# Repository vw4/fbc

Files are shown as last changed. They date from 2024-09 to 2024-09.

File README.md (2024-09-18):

# Footwell Backlight Controller

- Independent two-channel control with smooth fade transitions
- Delayed switch-off feature (can be disabled via T58b input)
- Low power standby mode

## Schematics

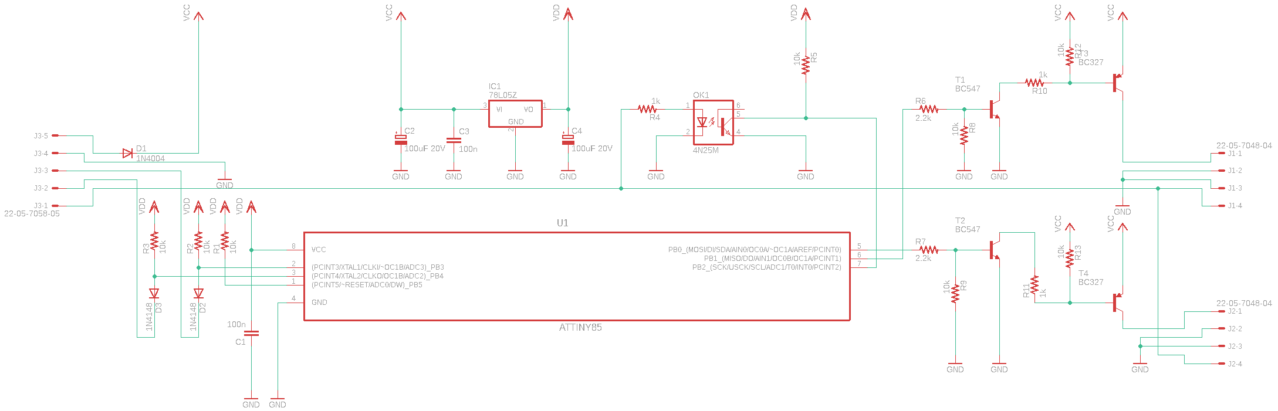
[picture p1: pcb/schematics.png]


## Partlist

### PCB

There are known issues with PCB layout

- The distance between the 4-pin connectors and the mounting holes is shorter by 0.5mm.
- All connectors need to be moved outward by 3.6mm to match the case outline.
- There are errors in the positions of the J1 and J2 labels on the silkscreen; the labels are placed on the solder pads.
- D1 is too close to the J3 connector housing.

| Qty | Value | Device | Package | Parts | Description | MF MPN | OC_FARNELL | OC_NEWARK | PACKAGE  | SUPPLIER |
|-----|---|---|---|---|---|---|---|---|---|---|
| 2 | 100n | Capacitor | C025-025X050 | C1, C3 | ceramic or polyester capacitor | | | | | |
| 2 | 100uF 20V | Capacitor | E3,5-8 | C2, C4 | electrolytic capacitor | | | | | |
| 8 | 10k | Resistor | 0207/10 | R1, R2, R3, R5, R8, R9, R12, R13 | 1/4 Watt, ±5% | | | | | |
| 1 | 1N4004 | 1N4004 | DO41-10 | D1 | DIODE | | | | | |
| 2 | 1N4148 | 1N4148 | DO35-10 | D2, D3 | DIODE | | | | | |
| 3 | 1k | Resistor | 0207/10 | R4, R10, R11 | 1/4 Watt, ±5% | | | | | |
| 2 | 2.2k | Resistor | 0207/10 | R6, R7 | 1/4 Watt, ±5% | | | | | |
| 2 | 5-104935-6 | Connector | 7395-04 | J1, J2 | CONNECTOR - LATCHING HDR SHRD 5P W/O HOLD-DN 30AU CNT | 5-104935-6 | | | | TE Connectivity |
| 1 | 5-104935-6 | Connector | 7395-05 | J3 | CONNECTOR - LATCHING HDR SHRD 4P W/O HOLD-DN 30AU CNT | 5-104935-1 | | | | TE Connectivity |
| 1 | 4N25M | 4N25M | DIL06 | OK1 | General Purpose 6-Pin Phototransistor Optocouplers | 4N25-M | 1021349 | 98K9084 | | |
| 1 | 78L05Z | 78L05Z | TO92 | IC1 | Positive VOLTAGE REGULATOR | | | | | |
| 1 | ATTINY85 | ATTINY85-20PU | DIP254P762X533-8 | U1 | 8-bit Microcontroller with In-System Programmable Flash | ATTINY85-20PU | 1455162 | 58M3796 | PDIP-8 | Atmel |
| 2 | BC327 | BC32725TA | TO92-EBC | T3, T4 | PNP Transistor | | | | | |
| 2 | BC547 | BC547CTA | TO92-CBE | T1, T2 | NPN Transistor | | | | | |

### Wiring

| Qty | Mfr. | Mfr. No. | Description |
|-----|---|---|---|
| 2 | TE Connectivity | 104257-3 | RECEPTACLE ASSY 4P  |
| 1 | TE Connectivity | 104257-4 | RECEPTACLE ASSY 5P  |
| 13  | TE Connectivity | 104479-3 | CONTACT SHORT 24-20 |
| - | | | 20 AWG wire |

### Enclosure

M3 threads need to be tapped in the bottom part. Assembly requires M3x20mm bolts.

| Printing method | Material | Color | Layer height | Infill |
|---|---|---|---|---|
| FDM | ABS | Black | 0.1 mm | 40% |

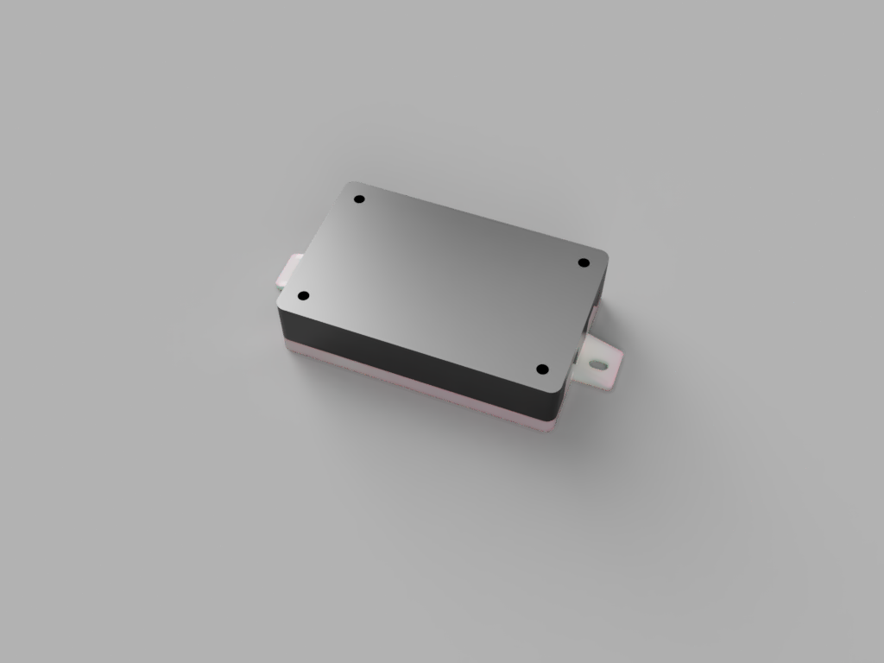
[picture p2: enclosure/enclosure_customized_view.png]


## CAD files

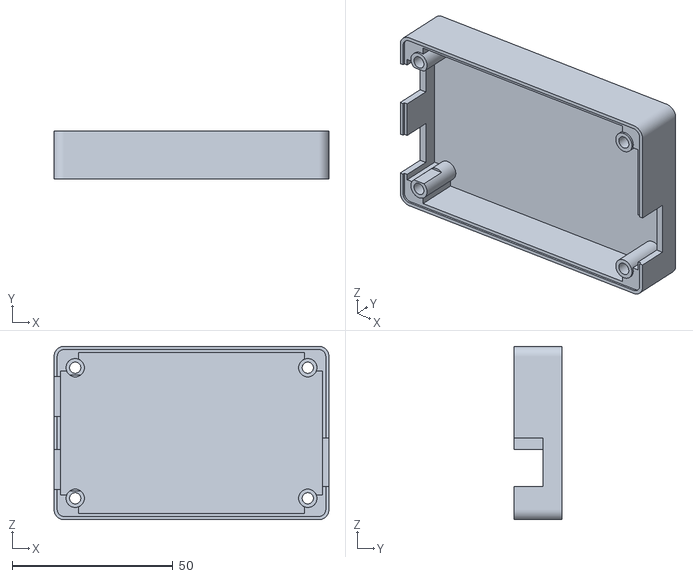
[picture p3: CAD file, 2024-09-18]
enclosure/fbc_1_enclosure_top.stl
85.6 x 15.0 x 54.0

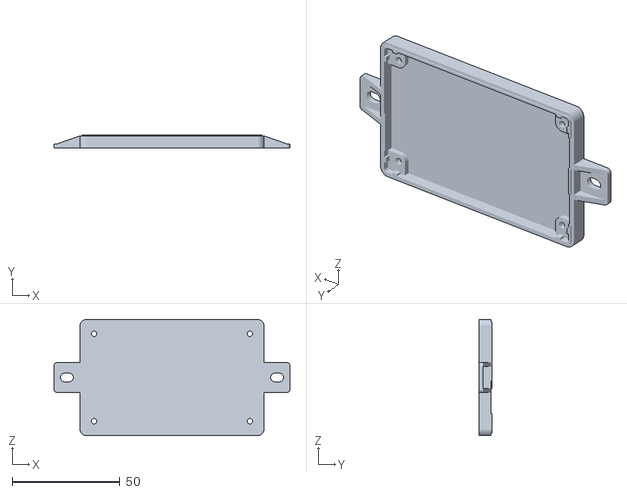
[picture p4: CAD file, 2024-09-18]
enclosure/fbc_1_enclosure_bottom.stl
109.6 x 6.20 x 54.0

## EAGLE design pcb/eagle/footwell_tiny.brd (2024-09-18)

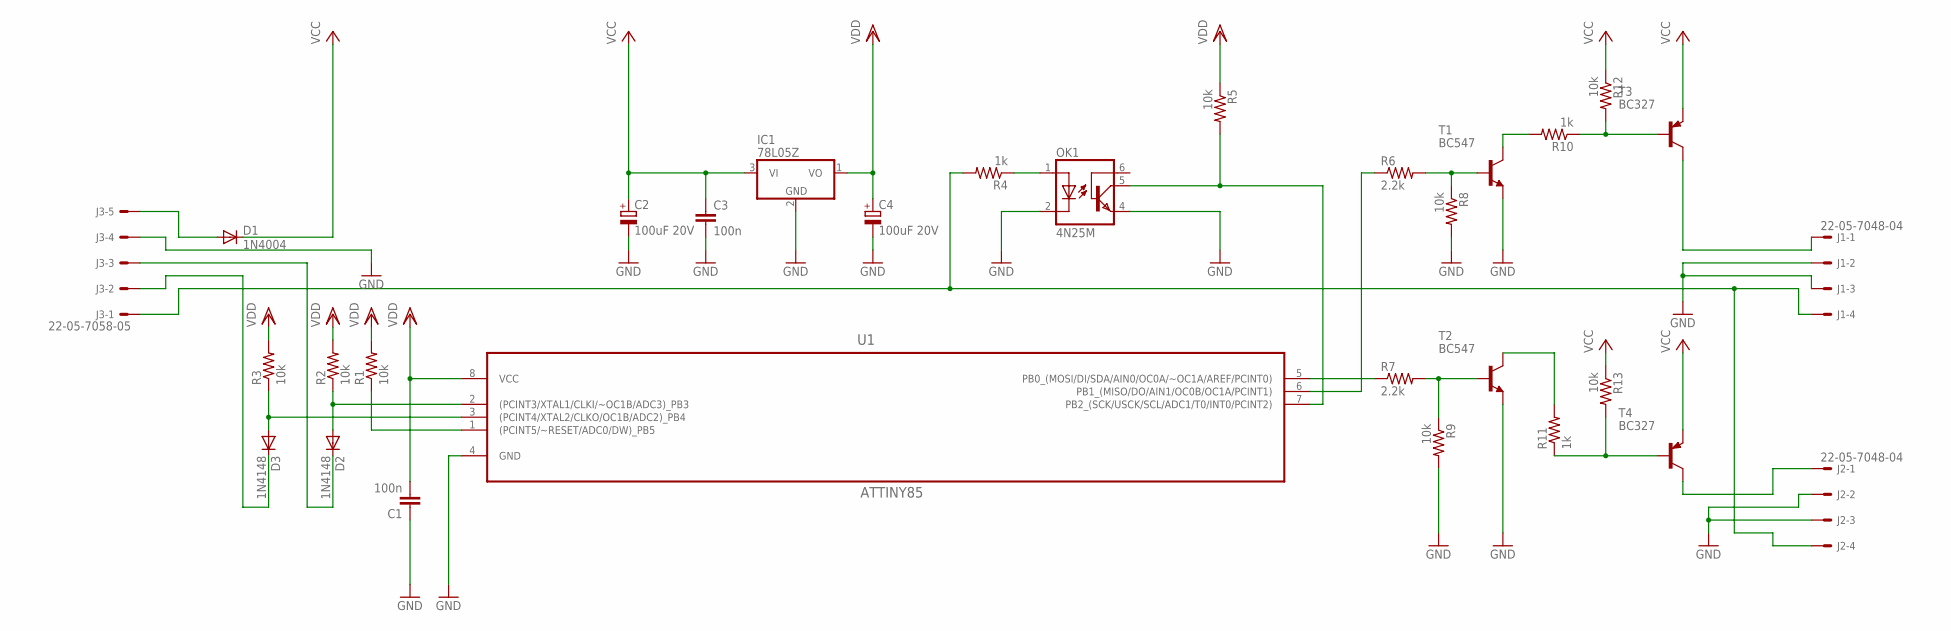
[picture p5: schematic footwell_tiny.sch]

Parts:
C1, C3: 100n; C025-025X050
C2, C4: 100uF 20V; E3,5-8
D1: 1N4004; DO41-10
D2, D3: 1N4148; DO35-10
IC1: 78L05Z; TO92
J1, J2: 22-05-7048-04; 7395-04
J3: 22-05-7058-05; 7395-05
OK1: 4N25M; DIL06
R1, R2, R3, R5, R8, R9, R12, R13: 10k; 0207/10
R4, R10, R11: 1k; 0207/10
R6, R7: 2.2k; 0207/10
T1, T2: BC547; TO92-CBE
T3, T4: BC327; TO92-EBC
U1: ATTINY85; DIP254P762X533-8

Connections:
DOOR0: D2.C, J3.3
DOOR1: D3.C, J3.2
GND: C1.1, C2.-, C3.2, C4.-, IC1.2 (GND), J1.2, J1.3, J2.2, J2.3, J3.4, OK1.2 (C), OK1.4 (EMI), R8.2, R9.2, T1.E, T2.E, U1.4 (GND)
unnamed: R1.1, U1.1 ((PCINT5/~RESET/ADC0/DW)_PB5)
unnamed: R10.1, R12.2, T3.B
unnamed: R10.2, T1.C
unnamed: R6.2, R8.1, T1.B
unnamed: R11.1, R13.2, T4.B
unnamed: R11.2, T2.C
unnamed: R7.2, R9.1, T2.B
unnamed: R6.1, U1.6 (PB1_(MISO/DO/AIN1/OC0B/OC1A/PCINT1))
unnamed: R7.1, U1.5 (PB0_(MOSI/DI/SDA/AIN0/OC0A/~OC1A/AREF/P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)
unnamed: OK1.1 (A), R4.1
unnamed: OK1.5 (COL), R5.2, U1.7 (PB2_(SCK/USCK/SCL/ADC1/T0/INT0/PCINT2))
unnamed: J1.4, J2.4, J3.1, R4.2
unnamed: J2.1, T4.C
unnamed: J1.1, T3.C
unnamed: D1.A, J3.5
PB3: D2.A, R2.1, U1.2 ((PCINT3/XTAL1/CLKI/~OC1B/ADC3)_PB3)
PB4: D3.A, R3.1, U1.3 ((PCINT4/XTAL2/CLKO/OC1B/ADC2)_PB4)
VCC: C2.+, C3.1, D1.C, IC1.3 (VI), R12.1, R13.1, T3.E, T4.E
VDD: C1.2, C4.+, IC1.1 (VO), R1.2, R2.2, R3.2, R5.1, U1.8 (VCC)

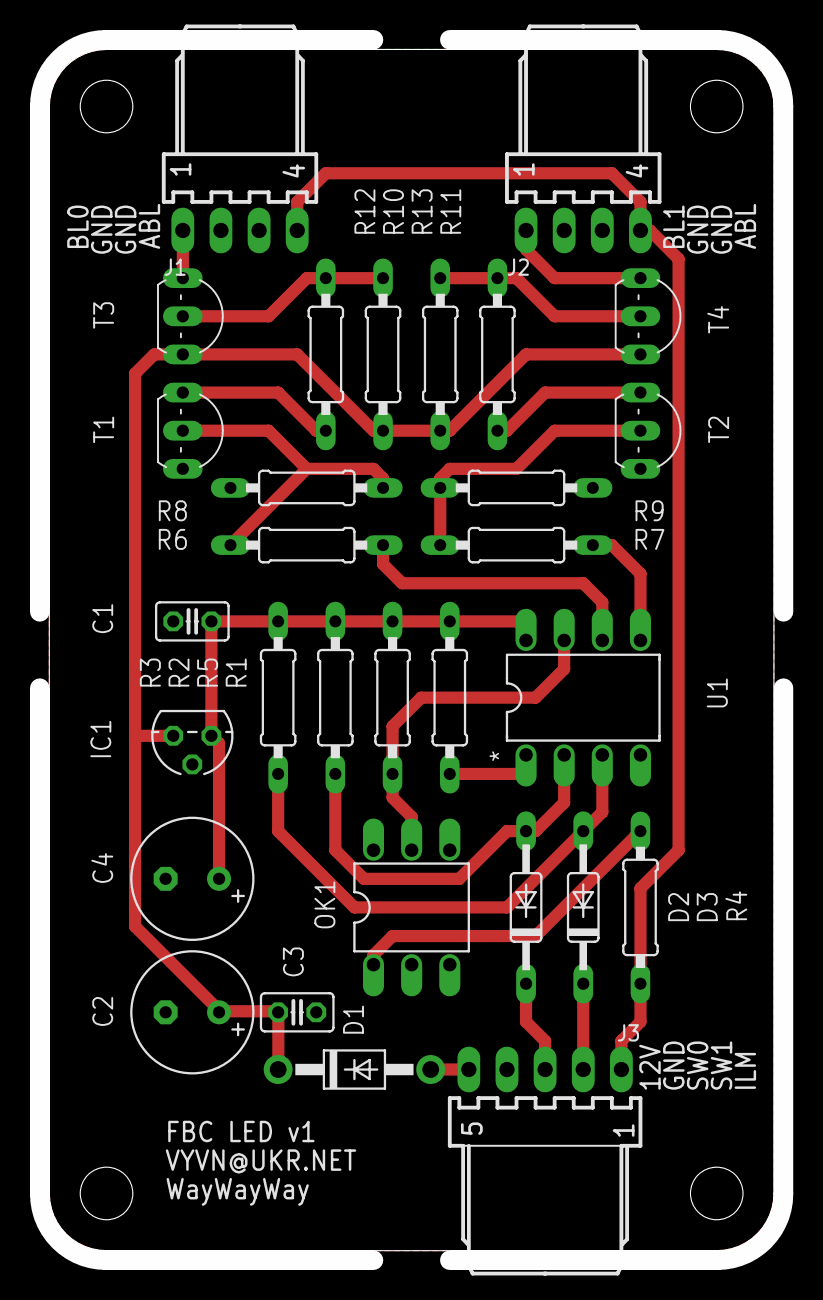
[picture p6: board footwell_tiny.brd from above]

Board: 2 copper layers, 49.5 x 81.3 mm, 30 parts (0 on the bottom side), 22 nets.

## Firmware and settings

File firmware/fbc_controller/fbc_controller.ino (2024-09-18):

/**
 * Footwell Backlight Controller
 * 
 *   - Independent two-channel control with smooth fade transitions
 *   - Delayed switch-off feature (can be disabled via T58b input)
 *   - Low power standby mode
 * 
 *   Atmel ATtiny25/45/85 Pinout
 * 
 *                                ┌───────u───────┐
 *          PCINT5/RESET/ADC0/dW ─┤ 1 PB5   VCC 8 ├─ 
 *   PCINT3/XTAL1/CLKI/OC1B/ADC3 ─┤ 2 PB3   PB2 7 ├─ SCK/USCK/SCL/ADC1/T0/INT0/PCINT2
 *   PCINT4/XTAL2/CLKO/OC1B/ADC2 ─┤ 3 PB4   PB1 6 ├─ MISO/DO/AIN1/OC0B/OC1A/PCINT1
 *                               ─┤ 4 GND   PB0 5 ├─ MOSI/DI/SDA/AIN0/OC0A/OC1A/AREF/PCINT0
 *                                └───────────────┘
 *   Pins General Info
 * 
 *           ┌─────────┬───────────┬─────────────┬─────────────┬─────────┐
 *           │ IC Lead │ Atmel Pin │ Arduino Pin │ Arduino ISP │ Purpose │
 *           ├─────────┼───────────┼─────────────┼─────────────┼─────────┤
 *           │    1    │    PB5    │             │     10      │   RST   │
 *           │    2    │    PB3    │ (D 3) Ain3  │             │   SW0   │
 *           │    3    │    PB4    │ (D 4) Ain2  │             │   SW1   │
 *           │    5    │    PB0    │ (D 0) pwm0  │     11      │   BL1   │
 *           │    6    │    PB1    │ (D 1) pwm1  │     12      │   BL0   │
 *           │    7    │    PB2    │ (D 2) Ain1  │     13      │   ILM   │
 *           └─────────┴───────────┴─────────────┴─────────────┴─────────┘
 * 
 *   Programming ATtiny25/45/85 with Arduino ISP
 *     1. Install attiny core files: https://github.com/damellis/attiny
 *     2. Prepare an Arduino:
 *       Examples > 11. ArduinoISP > ArduinoISP
 *       Sketch > Upload
 *     3. Wire ISP
 *       Arduino > ATtiny25/45/85
 *       5V      > VCC
 *       GND     > GND
 *       13      > PB2
 *       12      > PB1
 *       11      > PB0
 *       10      > RST
 *     4. Tools > Clock: "Internal 8MHz"
 *     5. Tools > Burn Bootloader
 *     6. Sketch > Upload Using Programmer
 *
 *   Fuses
 *     https://www.engbedded.com/fusecalc/?P=ATtiny25&V_LOW=0xE2&V_HIGH=0xDF&V_EXTENDED=0xFF&O_HEX=Apply+values
 * 
 *   Controller States
 * 
 *                                     ┌─────┐
 *              ┌──←─ door opened ─←───┤ OFF ├─← fade down completed ─┐
 *              │                      └─────┘                        │
 *              ↓          ┌──────←─ door opened ─←───────┐           ↑
 *         ┌────┴──────────┴────┐                   ┌─────┴───────────┴─────┐
 *         │ FADE_BACKLIGHT_UP  ├─→─ door closed ─→─┤  FADE_BACKLIGHT_DOWN  │
 *         └──────────┬─────────┘                   └───────────┬───────────┘
 *  fade up completed ↓                                         ↑ delay completed or illumination is on                     
 *            ┌───────┴───────┐                        ┌── ─────┴─────────┐
 *            │ BACKLIGHT_ON  ├───→─ door closed ─→────┤ SWITCH_OFF_DELAY │
 *            └───────┬───────┘                        └────────┬─────────┘
 *                    └───────────←─ door opened ─←─────────────┘
 */

#define ILLUMINATION_INPUT 2

#define FADE_STEP 1
#define SWITCH_OFF_DELAY_VALUE 15000

bool isIlluminationActive() {
  return digitalRead(ILLUMINATION_INPUT) == LOW;
}

enum StateLevel {
  OFF,
  FADE_BACKLIGHT_UP,
  BACKLIGHT_ON,
  SWITCH_OFF_DELAY,
  FADE_BACKLIGHT_DOWN,
};

struct channel {
  uint8_t inputPin;
  uint8_t backlightOutputPin;

  StateLevel state = OFF;
  uint8_t backlightValue = 0;
  uint16_t switchOffDelay = 0;

  bool previousInputValue = false;
  bool previousIlluminationValue = false;

  channel(uint8_t inputPin, uint8_t backlightOutputPin): inputPin(inputPin), backlightOutputPin(backlightOutputPin) {}
  
  bool isInputActive() {
    return digitalRead(inputPin) == LOW;
  }

  bool isInputsChanged() {
    return isInputActive() ^ previousInputValue || isIlluminationActive() ^ previousIlluminationValue;
  }

  bool isOff() {
    return state == OFF;
  }

  bool isFading() {
    return state == FADE_BACKLIGHT_UP || state == FADE_BACKLIGHT_DOWN;
  }

  bool isDelay() {
    return state == SWITCH_OFF_DELAY;
  }

  void setup() {
    setupInputPin(inputPin);
    digitalWrite(backlightOutputPin, LOW);
    pinMode(backlightOutputPin, OUTPUT);
    if (isInputsChanged()) {
      onChange();
    }
  }

  void writeOutput() {    
    analogWrite(backlightOutputPin, backlightValue);
    setNextBacklightValue();
  }

  void setNextBacklightValue() {
    if (state == FADE_BACKLIGHT_UP) {
      if (backlightValue != 255) {
        backlightValue = min(255, backlightValue + FADE_STEP);
      } else {
        onChange();
      }
    } else if (state == FADE_BACKLIGHT_DOWN) {
      if (backlightValue != 0) {
        backlightValue = max(0, backlightValue - FADE_STEP);
      } else {
        onChange();
      }
    }
  }

  void decrementSwitchOffDelay() {
    if (switchOffDelay > 0) {
      switchOffDelay = max(switchOffDelay - 4, 0);
    } else if (state == SWITCH_OFF_DELAY) {      
      onChange();
    }
  }

  void onChange() {
    switch (state) {
      case OFF:
      case FADE_BACKLIGHT_DOWN:
        if (isInputActive()) {
          state = FADE_BACKLIGHT_UP;
        } else if (backlightValue == 0) {
          state = OFF;
        }
        break;

      case FADE_BACKLIGHT_UP:
        if (!isInputActive()) {
          state = FADE_BACKLIGHT_DOWN;
        } else if (backlightValue == 255) {
          state = BACKLIGHT_ON;
        }
        break;

      case BACKLIGHT_ON:
        if (!isInputActive()) {
          if (isIlluminationActive()) {
            state = FADE_BACKLIGHT_DOWN;
          } else {
            switchOffDelay = SWITCH_OFF_DELAY_VALUE;
            state = SWITCH_OFF_DELAY;
          }
        }
        break;

      case SWITCH_OFF_DELAY:        
        if (isInputActive()) {
          state = BACKLIGHT_ON;
        } else if (isIlluminationActive() || switchOffDelay == 0) {
          state = FADE_BACKLIGHT_DOWN;
        }
        break;
    }
    previousInputValue = isInputActive();
    previousIlluminationValue = isIlluminationActive();
  }
};

#define CH_COUNT 2
channel channels[CH_COUNT] = {{3, 1}, {4, 0}};

void setupTimer1() {
  // millis();
  // Clear registers
  TCNT1 = 0;  
  // CTC and Prescaler 128
  TCCR1 = (1 << CTC1) | (1 << CS13);
  // 255.10204081632654 Hz (8000000/((244+1)*128))
  OCR1C = 255;
  // interrupt COMPA
  OCR1A = OCR1C;
  // Output Compare Match A Interrupt Enable
  TIMSK |= (1 << OCIE1A);
}

void setupInputPin(uint8_t inputPin) {
  pinMode(inputPin, INPUT_PULLUP);
  *digitalPinToPCMSK(inputPin) |= (1<<digitalPinToPCMSKbit(inputPin));
  *digitalPinToPCICR(inputPin) |= (1<<digitalPinToPCICRbit(inputPin));
}

void setupPowerSaveMode() {
  // Disable ADC
  ADCSRA &= ~(1<<ADEN);
  PRR |= 1 << PRADC;
  // Power down mode and sleep enable
  MCUCR |= 1 << SM1 | 1 << SE;
}

ISR(TIMER1_COMPA_vect) {
  if (channels[0].isOff() && channels[1].isOff()) {
    sei();
    asm volatile("sleep");
    return;
  }

  for (uint8_t i = 0; i < CH_COUNT; i++) {
    if (channels[i].isFading()) {
      channels[i].writeOutput();
    } else if (channels[i].isDelay()) {
      channels[i].decrementSwitchOffDelay();
    }
  }
}

ISR (PCINT0_vect) {
  for (uint8_t i = 0; i < CH_COUNT; i++) {
    if (channels[i].isInputsChanged()) {
      channels[i].onChange();
    }
  }
}

void setup() {
  cli();
  setupPowerSaveMode();
  setupInputPin(ILLUMINATION_INPUT);
  channels[0].setup();
  channels[1].setup();
  setupTimer1();
  sei();
}

void loop() {
  // put your main code here, to run repeatedly:
}
